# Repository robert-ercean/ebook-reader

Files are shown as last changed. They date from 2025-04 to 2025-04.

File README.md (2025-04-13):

# Block Diagram
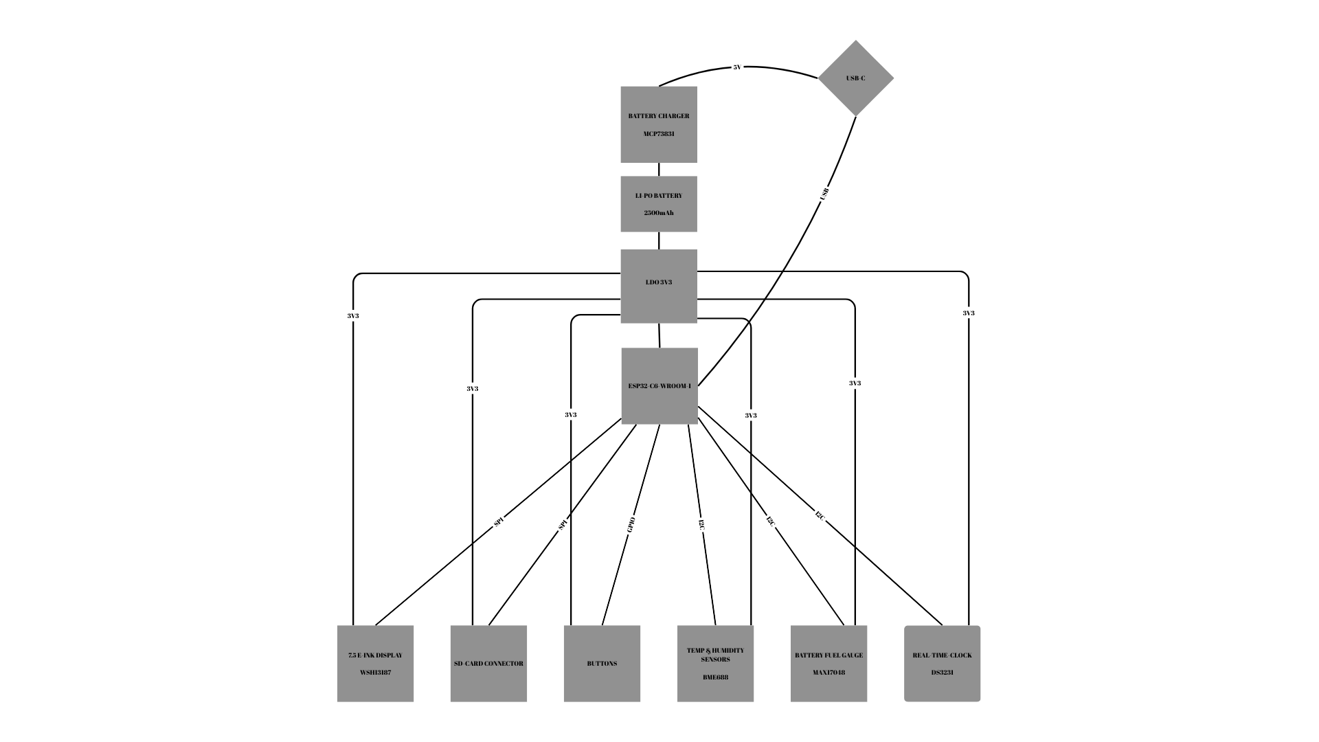
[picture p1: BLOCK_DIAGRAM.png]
Block Diagram


# Hardware Features – Detailed Description

## 1. Microcontroller – ESP32-C6

- **Processor:** 32-bit RISC-V core, clocked up to 160 MHz.
- **Memory:** 512KB internal SRAM and 8MB external flash memory (model W25Q512JVEIQ).
- **Connectivity:** Supports Wi-Fi 6 (802.11ax), Bluetooth Low Energy 5, and USB 2.0 (full-speed).
- **Interfaces:** SPI, I²C, UART, and multiple available GPIOs.
- **Power Efficiency:** Power-saving modes, including deep sleep.

## 2. E-Paper Display – 7.5”

- **Model:** Waveshare or equivalent, with a resolution of 800×480 pixels.
- **Connection:** 4-wire SPI plus control pins (CS, DC, RST, BUSY).
- **Power Consumption:** Very low in static mode; during refresh, consumption ranges between 15–25mA.

## 3. Environmental Sensor – BME688

- **Measurements:** Temperature, relative humidity, atmospheric pressure, and air quality (eCO2/VOC).
- **Interface:** I²C protocol at 400kHz (SDA/SCL).
- **Power Consumption:** Approx. 2.1µA in standby, with peaks of a few mA when active.

## 4. Power Supply and Management System

- **Battery:** Li-Po 3.7V, 2500mAh capacity.
- **Charging:** MCP73831 – simple and reliable IC for USB-C charging, up to 1A.
- **Monitoring:** MAX17048 – fuel gauge providing voltage and battery level data.
- **Voltage Regulation:** LDO such as XC6220A331MR-G, for a stable 3.3V output.

**Why these components?**
- MCP73831 offers a compact and efficient solution.
- MAX17048 enables precise battery monitoring and low-level warnings.

## 5. Buttons – 3 units

- **Type:** Tactile switch (Panasonic or similar).
- **Purpose:** Menu navigation, page turning, option selection.
- **Connection:** To GPIOs, with hardware (RC) or software debouncing.

## 6. USB-C Connector

- **Purpose:** Power/charging + data transfer via USB 2.0.
- **Protection:** ESD (e.g., USBLC6-2SC6Y) and termination resistors.
- **Options:** Supports firmware updates via USB or OTA via Wi-Fi.

## 7. Qwiic Interface (I²C)

- **Pins:** VCC, GND, SDA, SCL.
- **Functionality:** Quick expansion with additional I²C sensors/modules.

## 8. SD Card Slot – 112A-TAAR-R03

- **Purpose:** Storing e-books, logs, or firmware files.
- **Connection:** SPI or SDIO, depending on implementation.

## 9. Real-Time Clock – DS3231

- **Purpose:** Precise timekeeping, even without main power.
- **Communication:** I²C (shared with other sensors).
- **Backup:** Supercapacitor or secondary battery.

## 10. Additional Memory

- **Model:** W25Q512JVEIQ – external flash memory.
- **Connection:** Dedicated SPI (quad SPI) for firmware and large files.

---

# 4. ESP32-C6 Pin Allocation

| ESP32-C6 Pin | Signal | Detailed |
|---|---|---|
| GPIO1 | I²C SDA | Data line for sensors and RTC |
| GPIO2 | I²C SCL | Clock line for I²C interface |
| GPIO5 | SPI MISO | Data input from e-paper |
| GPIO6 | SPI MOSI | Data output to e-paper |
| GPIO7 | SPI CLK | Clock signal for SPI |
| GPIO8 | SPI CS (e-paper) | Chip select for display |
| GPIO9 | E-paper DC | Switch between data and command modes |
| GPIO10 | E-paper RST | Hardware reset for the display |
| GPIO11 | E-paper BUSY | Status signal (busy/free) |
| GPIO12 | Button 1 | Digital input for NEXT |
| GPIO13 | Button 2 | Digital input for PREV |
| GPIO14 | Button 3 | Digital input for OK/MENU |
| GPIO15 | MAX17048 ALERT (optional) | Low battery alert |
| GPIO16 | USB D+ | USB data line (fixed pin) |
| GPIO17 | USB D- | USB data line (fixed pin) |
| GPIO18 | Status LED (optional) | Visual indicator for various states |
| GPIO19 | SD Card CS | Chip select for SD card (SPI) |
| GPIO20 | SD Card MISO | Data received from SD card |
| GPIO21 | SD Card MOSI | Data sent to SD card |
| GPIO4 | SD Card CLK | SPI clock line for SD communication |

---

# Power Consumption Estimate

| Module | Typical Consumption |
|---|---|
| ESP32-C6 active | ~80mA with Wi-Fi / <10mA idle |
| E-paper (refresh) | 15–25mA |
| BME688 active | up to 3.6mA / 2.1µA standby |
| MAX17048 | Approx. 50µA |
| DS3231 | ~3.5mA active / <1µA backup |
| MCP73831 | Varies based on charging current|

**Usage Scenarios:**
- In **deep sleep**, total consumption can drop below 100µA.
- In active mode with Wi-Fi and screen refresh, consumption may reach 100–150mA.
- A 2500mAh battery allows for **weeks of operation** in predominantly passive mode (static display, infrequent Wi-Fi activity).

---

# Bill of Materials:

| Component | Type | Marketplace | Datasheet |
|---|---|---|---|
| EAGLE-LTSPICE_CC0402 | Capacitor | [Link](https://eu.mouser.com/ProductDetail/KEMET/C0402C475K8PACTU?qs=ulEaXIWI0c9ebKRT3r3htg%3D%3D) | [Datasheet](https://eu.mouser.com/datasheet/2/447/KEM_C1006_X5R_SMD-3316465.pdf) |
| ESP32_WROVER_EAGLE-LTSPICE_RR0402 | Resistor | [Link](https://eu.mouser.com/ProductDetail/Vishay-Beyschlag/MCS04020D9101BE000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) | [Datasheet](https://www.vishay.com/docs/28700/mcx0x0xpre.pdf) |
| RCL_CPOL-EUCT3528 | Capacitor | [Link](https://eu.mouser.com/ProductDetail/Nichicon/LGN2W101MELA25?qs=Fe64Qgzkstf1zMszMsgRoA%3D%3D) | [Datasheet](https://eu.mouser.com/datasheet/2/293/e_lgn-3082370.pdf) |
| ADAFRUIT_LEDCHIP-LED0603 | LED | [Link](https://eu.mouser.com/ProductDetail/ams-OSRAM/KG-EELP41.22-PHRH-35-A8J8-20-R18?qs=ZcfC38r4Posajg8ZvCDQkg%3D%3D) | [Datasheet](https://eu.mouser.com/datasheet/2/588/KG_EELP41_22_EN-3572852.pdf) |
| CPH3225A | Capacitor | [Link](https://eu.mouser.com/ProductDetail/Seiko-Semiconductors/CPH3225A?qs=3etwrb1wR%252BhUOph6lAO7eg%3D%3D) | [Datasheet](https://eu.mouser.com/datasheet/2/360/Seiko_Instruments_MicroBattery_E_20230330_2024Jan_-3561061.pdf) |
| ESP32_WROVER_SPARKFUN-DISCRETESEMI_MOSFET_PCH-DMG2305UX-7 | Transistor | [Link](https://eu.mouser.com/ProductDetail/Diodes-Incorporated/DMG2305UX-7?qs=L1DZKBg7t5F%2FNBHrjfxC%252Bg%3D%3D) | [Datasheet](https://www.diodes.com/assets/Datasheets/DMG2305UX.pdf) |
| ESP32_WROVER_AVX---SD0805S020S1R0_AVX_SD0805S020S1R0_0_0AVX_SD0805S020S1R0_0_0 | Diode | [Link](https://eu.mouser.com/ProductDetail/ROHM-Semiconductor/SCS310AMC7G?qs=iLKYxzqNS75xiccEgNnX2g%3D%3D) | [Datasheet](https://fscdn.rohm.com/en/products/databook/datasheet/discrete/sic/sbd/scs310am-e.pdf) |
| SI1308EDL-T1-GE3 | Transistor | [Link](https://eu.mouser.com/ProductDetail/Vishay-Semiconductors/SI1308EDL-T1-GE3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) | [Datasheet](https://www.vishay.com/docs/63399/si1308edl.pdf) |
| ESP32C6_VARISTORCN1812 | Varistor | [Link](https://eu.mouser.com/ProductDetail/Schurter/PFMF.050.2?qs=1auRipcfynCums5v1iucSA%3D%3D) | [Datasheet](https://eu.mouser.com/datasheet/2/358/typ_PFMF-1275918.pdf) |
| ESP32_WROVER_BME680_BME680 | Integrated Environmental Unit | [Link](https://eu.mouser.com/ProductDetail/M5Stack/U001-C?qs=e8oIoAS2J1R2mB7ZY1%252BSZg%3D%3D) | [Datasheet](https://docs.m5stack.com/en/unit/envIII) |
| ESP32-C6-WROOM-1-N8 | MicroController | [Link](https://eu.mouser.com/ProductDetail/Espressif-Systems/ESP32-C6?qs=Imq1NPwxi75noDtUpuVuWw%3D%3D) | [Datasheet](https://eu.mouser.com/datasheet/2/891/esp32_c6_datasheet_en-3304070.pdf) |
| 744043680IND_4828-WE-TPC_WRE | Inductor | [Link](https://eu.mouser.com/ProductDetail/Wurth-Elektronik/744043680?qs=PGXP4M47uW6VkZq%252BkzjrHA%3D%3D) | [Datasheet](https://www.we-online.com/components/products/datasheet/744043680.pdf) |
| SI1308EDL-T1-GE3 | Transistor | [Link](https://eu.mouser.com/ProductDetail/Vishay-Semiconductors/SI1308EDL-T1-GE3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) | [Datasheet](https://www.vishay.com/docs/63399/si1308edl.pdf) |
| BD5229G-TR | Voltage Detector | [Link](https://eu.mouser.com/ProductDetail/ROHM-Semiconductor/BD5229G-TR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) | [Datasheet](https://fscdn.rohm.com/en/products/databook/datasheet/ic/power/voltage_detector/bd52xxg-e.pdf) |
| DS3231SN# | RTC Module | [Link](https://eu.mouser.com/ProductDetail/Analog-Devices-Maxim-Integrated/DS3231SN?qs=1eQvB6Dk1vhUlr8%2FOrV0Fw%3D%3D) | [Datasheet](https://eu.mouser.com/datasheet/2/609/DS3231-3421123.pdf) |
| USBLC6-2SC6Y | ESD Protection | [Link](https://eu.mouser.com/ProductDetail/STMicroelectronics/USBLC6-2SC6Y?qs=gNDSiZmRJS%2FOgDexvXkdow%3D%3D) | [Datasheet](https://eu.mouser.com/datasheet/2/389/usblc6_2sc6y-1852505.pdf) |
| W25Q512JVEIQ | Flash Memory | [Link](https://eu.mouser.com/ProductDetail/Winbond/W25Q512JVEIQ?qs=l7cgNqFNU1jw6svr3at6tA%3D%3D) | [Datasheet](https://eu.mouser.com/datasheet/2/949/Winbond_W25Q512JV_Datasheet-3240039.pdf) |
| SAMACSYS_PARTS_USB4110-GF-A | USB Connector | [Link](https://eu.mouser.com/ProductDetail/GCT/USB4110-GF-A?qs=KUoIvG%2F9IlYiZvIXQjyJeA%3D%3D) | [Datasheet](https://eu.mouser.com/datasheet/2/837/GCT_USB4110_Product_Drawing___20k_cycles-3455479.pdf) |
| FH34SRJ | E-Paper Display Header | [Link](https://eu.mouser.com/ProductDetail/Hirose-Connector/FH34SRJ-7S-0.5SH50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) | [Datasheet](https://eu.mouser.com/datasheet/2/185/FH34SRJ_7S_0_5SH_50__CL0580_1200_0_50_2DDrawing_00-1615127.pdf) |
| MAX17048G+T10 | Battery Management | [Link](https://eu.mouser.com/ProductDetail/Analog-Devices-Maxim-Integrated/MAX17048G%2bT10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) | [Datasheet](https://eu.mouser.com/datasheet/2/609/MAX17048_MAX17049-3469099.pdf) |
| MCP73831 | Battery Controller | [Link](https://eu.mouser.com/ProductDetail/Microchip-Technology/MCP73831T-2ATI-MC?qs=yUQqVecv4qs9k7ug0bEXiw%3D%3D) | [Datasheet](https://eu.mouser.com/datasheet/2/268/MCP73831_Family_Data_Sheet_DS20001984H-3441711.pdf) |
| 112A-TAAR-R03_ATTEND | SD Card Mount | [Link](https://store.comet.srl.ro/Catalogue/Product/43497/) | [Datasheet](https://store.comet.srl.ro/Catalogue/Product/43497/) |
| XC6220A331MR-G | LDO Voltage Regulator | [Link](https://eu.mouser.com/ProductDetail/Torex-Semiconductor/XC6220A331MR-G?qs=AsjdqWjXhJ8ZSWznL1J0gg%3D%3D) | [Datasheet](https://eu.mouser.com/datasheet/2/760/xc6220-3371556.pdf) |

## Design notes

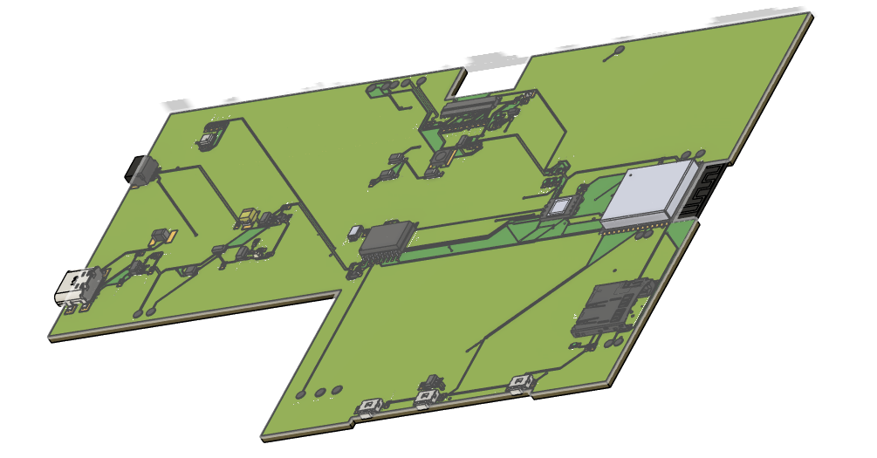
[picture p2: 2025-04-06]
Images/PCB/Board_1.png

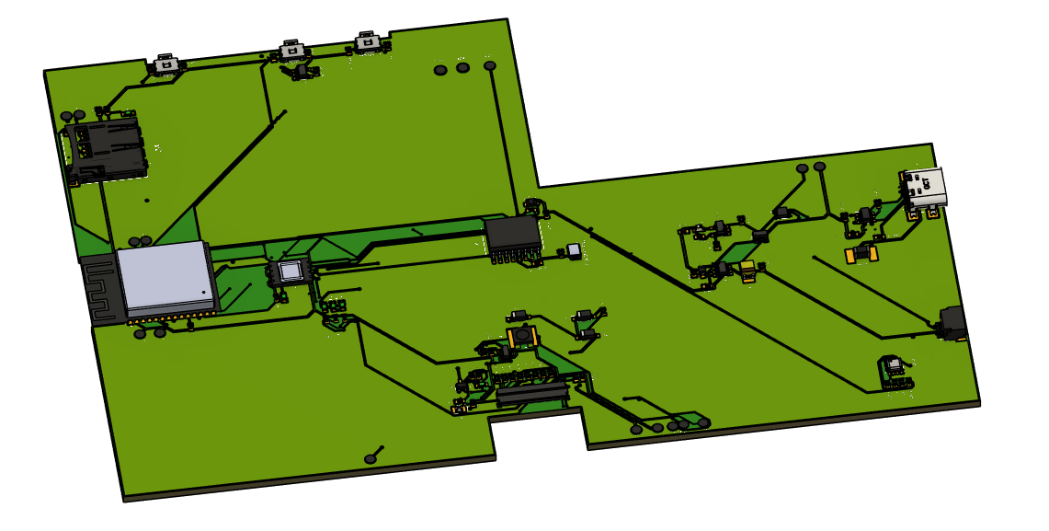
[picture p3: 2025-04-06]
Images/PCB/Board.png

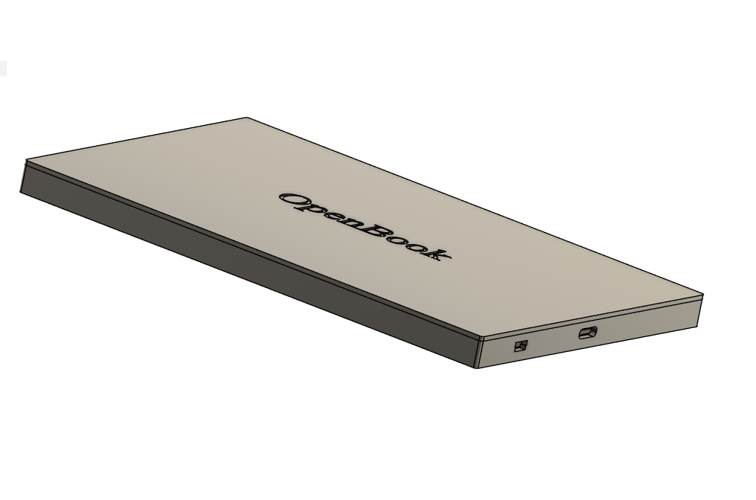
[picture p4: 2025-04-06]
Images/Device/Device_2.png

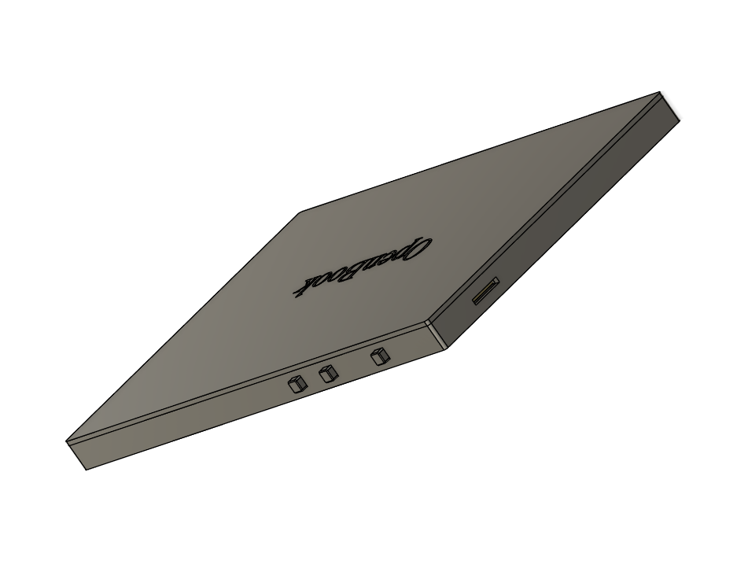
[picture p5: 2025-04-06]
Images/Device/Device_3.png

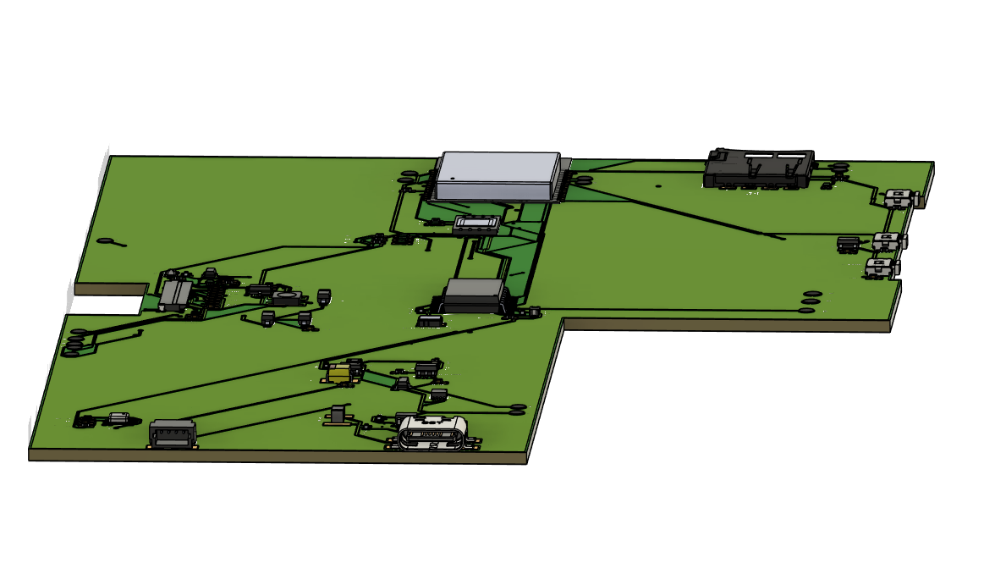
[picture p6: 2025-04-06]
Images/PCB/Board_2.png

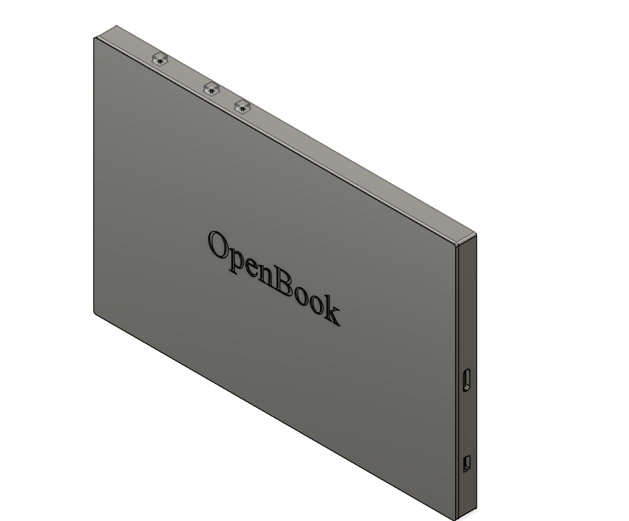
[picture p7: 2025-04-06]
Images/Device/Device.png

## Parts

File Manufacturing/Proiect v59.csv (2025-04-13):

Qty | Value | Device | Package | Parts | Description | ARROW_PART_NUMBER | ARROW_PRICE-STOCK | AVAILABILITY | CENTROID_NOT_SPECIFIED | CHECK_PRICES | COPYRIGHT | DATASHEET | DESCRIPTION | DIGIKEY_DESCRIPTION | DIGIKEY_PART_NUMBER | HEIGHT | LEAD_FREE | MANUFACTURER_NAME | MANUFACTURER_PART_NUMBER | MF | MFR_NAME | MOUSER_PART_NUMBER | MOUSER_PRICE-STOCK | MOUSER_TESTING_PART_NUMBER | MOUSER_TESTING_PRICE-STOCK | MP | MPN | PACKAGE | POPULARITY | PREFIX | PRICE | PROD_ID | PURCHASE-URL | ROHS | SNAPEDA_LINK | SPICEMODEL | SPICEPREFIX | TEMPERATURE_RANGE_HIGH | TEMPERATURE_RANGE_LOW | TP_SIGNAL_NAME | VALUE
1 |  | ADAFRUIT_LEDCHIP-LED0603 | ADAFRUIT_CHIP-LED0603 | CHG_LED | LED
1 |  | EAGLE-LTSPICE_CC0402 | EAGLE-LTSPICE_C0402 | C1_BAT | CAPACITOR, European symbol |  |  |  |  |  |  |  |  |  |  |  |  |  |  |  |  |  |  |  |  |  |  |  |  |  |  |  |  |  |  | NONE | C
1 |  | RCL_CPOL-EUCT3528 | RCL_CT3528 | C3 | POLARIZED CAPACITOR, European symbol |  |  |  |  |  |  |  |  |  |  |  |  |  |  |  |  |  |  |  |  |  |  |  | 0 |  |  |  |  |  |  |  | C
1 |  | SJ | SJ | SJ1 | SMD solder JUMPER |  |  |  |  |  |  |  |  |  |  |  |  |  |  |  |  |  |  |  |  |  |  |  | 3
1 | 0.1uF/50V | EAGLE-LTSPICE_CC0402 | EAGLE-LTSPICE_C0402 | EPD_C5 | CAPACITOR, European symbol |  |  |  |  |  |  |  |  |  |  |  |  |  |  |  |  |  |  |  |  |  |  |  |  |  |  |  |  |  |  | NONE | C
1 | 0.47 | ESP32_WROVER_EAGLE-LTSPICE_RR0402 | ESP32_WROVER_EAGLE-LTSPICE_R0402 | R3 | RESISTOR, European symbol |  |  |  |  |  |  |  |  |  |  |  |  |  |  |  |  |  |  |  |  |  |  |  |  |  |  |  |  |  |  | NONE | R
1 | 100K | ESP32_WROVER_EAGLE-LTSPICE_RR0402 | ESP32_WROVER_EAGLE-LTSPICE_R0402 | R1_PWRUSB | RESISTOR, European symbol |  |  |  |  |  |  |  |  |  |  |  |  |  |  |  |  |  |  |  |  |  |  |  |  |  |  |  |  |  |  | NONE | R
8 | 100nF | EAGLE-LTSPICE_CC0402 | EAGLE-LTSPICE_C0402 | C1, C2, C4_USB, C6, C8, C9, C10, C_DELAY | CAPACITOR, European symbol |  |  |  |  |  |  |  |  |  |  |  |  |  |  |  |  |  |  |  |  |  |  |  |  |  |  |  |  |  |  | NONE | C
16 | 10K | ESP32_WROVER_EAGLE-LTSPICE_RR0402 | ESP32_WROVER_EAGLE-LTSPICE_R0402 | R1, R1_PINH, R1_PINH1, R2-PINH, R2-PINH1, R4, R5, R6, R7, R8, R9, R10, R_BOOT, R_CHANGE, R_CL1, R_RESET | RESISTOR, European symbol |  |  |  |  |  |  |  |  |  |  |  |  |  |  |  |  |  |  |  |  |  |  |  |  |  |  |  |  |  |  | NONE | R
1 | 10uF | EAGLE-LTSPICE_CC0402 | EAGLE-LTSPICE_C0402 | C7 | CAPACITOR, European symbol |  |  |  |  |  |  |  |  |  |  |  |  |  |  |  |  |  |  |  |  |  |  |  |  |  |  |  |  |  |  | NONE | C
1 | 112A-TAAR-R03_ATTEND | 112A-TAAR-R03_ATTEND | 112ATAARR03ATTEND | J4 | Micro SD Card Socket, Push-Push Type, Top Mount, SMT, H=1.83mm, 10u |  |  |  |  |  |  |  | Micro SD Card Socket | Push-Push Type | Top Mount | SMT | H=1.83mm | 10u |  |  | 1.9mm |  | ATTEND | 112A-TAAR-R03 ATTEND
1 | 15 | ESP32_WROVER_EAGLE-LTSPICE_RR0402 | ESP32_WROVER_EAGLE-LTSPICE_R0402 | R_CAPACITOR | RESISTOR, European symbol |  |  |  |  |  |  |  |  |  |  |  |  |  |  |  |  |  |  |  |  |  |  |  |  |  |  |  |  |  |  | NONE | R
1 | 1uF | EAGLE-LTSPICE_CC0402 | EAGLE-LTSPICE_C0402 | C5 | CAPACITOR, European symbol |  |  |  |  |  |  |  |  |  |  |  |  |  |  |  |  |  |  |  |  |  |  |  |  |  |  |  |  |  |  | NONE | C
9 | 1uF/50V | EAGLE-LTSPICE_CC0402 | EAGLE-LTSPICE_C0402 | EPD_C1, EPD_C2, EPD_C6, EPD_C7, EPD_C8, EPD_C9, EPD_C10, EPD_C11, EPD_C12 | CAPACITOR, European symbol |  |  |  |  |  |  |  |  |  |  |  |  |  |  |  |  |  |  |  |  |  |  |  |  |  |  |  |  |  |  | NONE | C
1 | 2.2 | ESP32_WROVER_EAGLE-LTSPICE_RR0402 | ESP32_WROVER_EAGLE-LTSPICE_R0402 | R2 | RESISTOR, European symbol |  |  |  |  |  |  |  |  |  |  |  |  |  |  |  |  |  |  |  |  |  |  |  |  |  |  |  |  |  |  | NONE | R
1 | 200 | ESP32_WROVER_EAGLE-LTSPICE_RR0402 | ESP32_WROVER_EAGLE-LTSPICE_R0402 | R1_BAT | RESISTOR, European symbol |  |  |  |  |  |  |  |  |  |  |  |  |  |  |  |  |  |  |  |  |  |  |  |  |  |  |  |  |  |  | NONE | R
2 | 20V/4.2A/52mO/1.4W | ESP32_WROVER_SPARKFUN-DISCRETESEMI_MOSFET_PCH-DMG2305UX-7 | ESP32_WROVER_SPARKFUN-DISCRETESEMI_SOT23-3 | Q1, Q2 | P-channel MOSFETs |  |  |  |  |  |  |  |  |  |  |  |  |  |  |  |  |  |  |  |  |  |  |  |  |  |  | TRAN-14388 |  |  |  |  |  |  |  |  | 20V/4.2A/52mO/1.4W
1 | 2K | ESP32_WROVER_EAGLE-LTSPICE_RR0402 | ESP32_WROVER_EAGLE-LTSPICE_R0402 | R2_BAT | RESISTOR, European symbol |  |  |  |  |  |  |  |  |  |  |  |  |  |  |  |  |  |  |  |  |  |  |  |  |  |  |  |  |  |  | NONE | R
4 | 4.7uF | EAGLE-LTSPICE_CC0402 | EAGLE-LTSPICE_C0402 | C1_BAT1, C1_BAT2, C2_BAT, C5_USB | CAPACITOR, European symbol |  |  |  |  |  |  |  |  |  |  |  |  |  |  |  |  |  |  |  |  |  |  |  |  |  |  |  |  |  |  | NONE | C
1 | 4.7uF/25V | EAGLE-LTSPICE_CC0402 | EAGLE-LTSPICE_C0402 | C4 | CAPACITOR, European symbol |  |  |  |  |  |  |  |  |  |  |  |  |  |  |  |  |  |  |  |  |  |  |  |  |  |  |  |  |  |  | NONE | C
2 | 5K1 | ESP32_WROVER_EAGLE-LTSPICE_RR0402 | ESP32_WROVER_EAGLE-LTSPICE_R0402 | R2-USB, R2-USB1 | RESISTOR, European symbol |  |  |  |  |  |  |  |  |  |  |  |  |  |  |  |  |  |  |  |  |  |  |  |  |  |  |  |  |  |  | NONE | R
1 | 68uH | 744043680IND_4828-WE-TPC_WRE | IND_4828-WE-TPC_WRE | L1 |  |  |  |  |  |  | Copyright (C) 2024 Ultra Librarian. All rights reserved. |  |  |  |  |  |  |  | 744043680 |  | Wurth Electronics
1 | BD5229G-TR | BD5229G-TR | SOT95P280X125-5N | IC2 | Voltage Detector with Adjustable Delay Time: CMOS processes are utilized to develop high precision, low current consumption CMOS reset ICs that allow arbitrary setting of the delay time. The extensive lineup includes both Nch Open Drain and CMOS output types in a wide range of detection voltages (from 2.3V to 6.0V, in 0.1V steps), enabling selection of the ideal solution based on customer requirements. In addition, the entire series is of course both lead-free and RoHS-compliant. |  |  |  |  |  |  |  | Voltage Detector with Adjustable Delay Time: CMOS processes are utilized to develop high precision | low current consumption CMOS reset ICs that allow arbitrary setting of the delay time. The extensive lineup includes both Nch Open Drain and CMOS output types in a wide range of detection voltages (from 2.3V to 6.0V | in 0.1V steps) | enabling selection of the ideal solution based on customer requirements. In addition | the entire series is of course both lead-free and RoHS-compliant. |  |  | 1.25mm |  | ROHM Semiconductor | BD5229G-TR |  |  | 755-BD5229G-TR | https://www.mouser.co.uk/ProductDetail/ROHM-Semiconductor/BD5229G-TR?qs=4kLU8WoGk0vvnhrrYwdszw%3D%3D
3 | BUTTON_CUSYOMV1 | BUTTON_CUSYOMV1 | MYBUTTON | BOOT_BUTTON, CHANGE_BUTTON, RESET_BUTTON
1 | CPH3225A | CPH3225A | CAPCP3225X100N | C10_SUPERCAP | Cap 0.011F 3.3V 1210 Flat Check availability |  |  | Not in stock |  | https://www.snapeda.com/parts/CPH3225A/Seiko+Instruments/view-part/?ref=eda |  |  | 11 mF (EDLC) Supercapacitor 3.3 V 1210 (3225 Metric) - - |  |  |  |  |  |  | Seiko Instruments |  |  |  |  |  | CPH3225A |  | 1210 Seiko |  |  | None |  | https://www.snapeda.com/api/url_track_click_mouser/?unipart_id=562593&manufacturer=Seiko Instruments&part_name=CPH3225A&search_term=None |  | https://www.snapeda.com/parts/CPH3225A/Seiko+Instruments/view-part/?ref=snap
1 | DS3231SN# | DS3231SN# | SOIC127P1032X265-16N | U3 | Real Time Clock Serial 16-Pin SOIC W T/R Check availability |  |  | In Stock |  | https://www.snapeda.com/parts/DS3231SN%23/Analog+Devices/view-part/?ref=eda |  |  | Extremely Accurate I²C-Integrated RTC/TCXO/Crystal |  |  |  |  |  |  | Analog Devices |  |  |  |  |  | DS3231SN# |  | SOIC-16 Maxim |  |  | None |  | https://www.snapeda.com/api/url_track_click_mouser/?unipart_id=99048&manufacturer=Analog Devices&part_name=DS3231SN#&search_term=None |  | https://www.snapeda.com/parts/DS3231SN%23/Analog+Devices/view-part/?ref=snap
1 | ESP32-C6-WROOM-1-N8 | ESP32-C6-WROOM-1-N8 | XCVR_ESP32-C6-WROOM-1-N8 | U2 | Check availability |  |  | In Stock |  | https://www.snapeda.com/parts/ESP32-C6-WROOM-1-N8/Espressif+Systems/view-part/?ref=eda |  |  | Multiprotocol Modules ESP32-C6 module | Wi-Fi 6 in 2.4 GHz band | Bluetooth 5 | Zigbee 3.0 and Thread. ESP34-WROOM Compatible - ENGINEERING SAMPLE |  |  |  |  |  |  | Espressif Systems |  |  |  |  |  | ESP32-C6-WROOM-1-N8 |  | None |  |  | None |  |  |  | https://www.snapeda.com/parts/ESP32-C6-WROOM-1-N8/Espressif+Systems/view-part/?ref=snap
1 | ESP32C6_VARISTORCN1812 | ESP32C6_VARISTORCN1812 | ESP32C6_VARISTOR_CT/CN1812 | PFMF.050.1 | VARISTOR |  |  |  |  |  |  |  |  |  |  |  |  |  |  |  |  |  |  |  |  |  |  |  | 0
2 | ESP32_WROVER_AVX---SD0805S020S1R0_AVX_SD0805S020S1R0_0_0AVX_SD0805S020S1R0_0_0 | ESP32_WROVER_AVX---SD0805S020S1R0_AVX_SD0805S020S1R0_0_0AVX_SD0805S020S1R0_0_0 | ESP32_WROVER_AVX---SD0805S020S1R0_AVX_SD0805S020S1R0_0 | D1, D7 | Schottky Barrier Rectifier Diode |  |  |  | No |  |  | http://datasheets.avx.com/schottky.pdf |  | DIODE SCHOTTKY 20V 1A 0805 | 478-7800-1-ND |  | yes |  |  | AVX |  | 581-SD0805S020S1R0 |  |  |  |  |  | 0805 (2012 metric) |  | D |  |  |  | yes |  |  |  | +125°C | -55°C
1 | ESP32_WROVER_BME680_BME680 | ESP32_WROVER_BME680_BME680 | ESP32_WROVER_BME680_PSON80P300X300X100-8N | SENSOR2 | Integrated Environmental Unit |  |  | Unavailable |  |  |  |  | Integrated Environmental Unit |  |  |  |  |  |  | Bosch Sensortec |  |  |  |  |  | BME680 |  | LGA-8 Bosch Tools |  |  | None
1 | ESP32_WROVER_SPARKFUN-IC-POWER_MCP73831 | ESP32_WROVER_SPARKFUN-IC-POWER_MCP73831 | ESP32_WROVER_SPARKFUN-IC-POWER_SOT23-5 | MCP_73831 | MCP73831T Li-Ion, Li-Pol Controller |  |  |  |  |  |  |  |  |  |  |  |  |  |  |  |  |  |  |  |  |  |  |  |  |  |  | IC-09995
1 | FH34SRJ-24S-0.5SH_99_ | FH34SRJ-24S-0.5SH_99_ | FH34SRJ24S05SH99 | J1 | (0.50mm) Surface Mount, Right Angle |  |  |  |  |  |  |  | 24 Position FFC | FPC Connector Contacts | (0.50mm) Surface Mount | Right Angle |  |  | 1.1mm |  | Hirose | FH34SRJ-24S-0.5SH(99) |  |  | 798-FH34SRJ24S05SH99 | https://www.mouser.co.uk/ProductDetail/Hirose-Connector/FH34SRJ-24S-0.5SH99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
1 | MAX17048G+T10 | MAX17048G+T10 | SON50P200X200X80-9N | U1 | Check availability |  |  | In Stock |  | https://www.snapeda.com/parts/MAX17048G+T10/Analog+Devices/view-part/?ref=eda |  |  | 3µA 1-Cell/2-Cell Fuel Gauge with ModelGauge |  |  |  |  |  |  | Analog Devices |  |  |  |  |  | MAX17048G+T10 |  | TDFN-8 Maxim |  |  | None |  | https://www.snapeda.com/api/url_track_click_mouser/?unipart_id=329239&manufacturer=Analog Devices&part_name=MAX17048G+T10&search_term=None |  | https://www.snapeda.com/parts/MAX17048G+T10/Analog+Devices/view-part/?ref=snap
3 | MBR0530 | MBR0530 | SOD3716X135N | D3, D4, D5 | ON SEMICONDUCTOR - MBR0530 - DIODE, SCHOTTKY, 0.5A, 30V, SOD-123 |  |  | In Stock |  | https://www.snapeda.com/parts/MBR0530/Onsemi/view-part/?ref=eda |  |  | Diode Schottky 30 V 500mA Surface Mount SOD-123 |  |  |  |  |  |  | ON Semiconductor |  |  |  |  |  | MBR0530 |  | SOD-123-2 ON Semiconductor |  |  | None |  | https://www.snapeda.com/api/url_track_click_mouser/?unipart_id=179458&manufacturer=ON Semiconductor&part_name=MBR0530&search_term=None |  | https://www.snapeda.com/parts/MBR0530/Onsemi/view-part/?ref=snap
6 | PGB1010603MR | PGB1010603MR | DIOC1608X36N | D6, D8, D9, D10, D11, D12 | Check availability |  |  | In Stock |  | https://www.snapeda.com/parts/PGB1010603MR/Littelfuse/view-part/?ref=eda |  |  | 150V (Typ) Clamp - Ipp Tvs Diode Surface Mount 0603 (1608 Metric) |  |  |  |  |  |  | Littelfuse Inc. |  |  |  |  |  | PGB1010603MR |  | 0603 Littelfuse Inc. |  |  | None |  | https://www.snapeda.com/api/url_track_click_mouser/?unipart_id=5659453&manufacturer=Littelfuse Inc.&part_name=PGB1010603MR&search_term=None |  | https://www.snapeda.com/parts/PGB1010603MR/Littelfuse/view-part/?ref=snap
1 | QWIIC_RIGHT_ANGLE | QWIIC_CONNECTORJS-1MM | JST04_1MM_RA | J3 | SparkFun I2C Standard Qwiic Connector |  |  |  |  |  |  |  |  |  |  |  |  |  |  |  |  |  |  |  |  |  |  |  |  |  |  | CONN-13694 |  |  |  |  |  |  |  |  | QWIIC_RIGHT_ANGLE
1 | SAMACSYS_PARTS_USB4110-GF-ACPLM | SAMACSYS_PARTS_USB4110-GF-ACPLM | SAMACSYS_PARTS_USB4110GFA | J2 | CONN USB 2.0 TYPE-C R/A SMT
1 | SI1308EDL-T1-GE3 | SI1308EDL-T1-GE3 | SOT65P210X110-3N | Q3 | MOSFET N-Ch 30V 1.5A TrenchFET SC70 Vishay Si1308EDL-T1-GE3 N-channel MOSFET Transistor, 1.5 A, 30 V, 3-Pin SC-70 |  |  | In Stock |  | https://www.snapeda.com/parts/SI1308EDL-T1-GE3/Vishay+Siliconix/view-part/?ref=eda |  |  | Si1308EDL-T1-GE3 N-channel MOSFET Transistor | 1.5 A | 30 V | 3-Pin SC-70 | Siliconix / Vishay SI1308EDL-T1-GE3 |  |  |  |  |  |  | Vishay Siliconix |  |  |  |  |  | SI1308EDL-T1-GE3 |  | SOT-323 Vishay Semiconductor |  |  | None |  | https://www.snapeda.com/api/url_track_click_mouser/?unipart_id=274603&manufacturer=Vishay Siliconix&part_name=SI1308EDL-T1-GE3&search_term=None |  | https://www.snapeda.com/parts/SI1308EDL-T1-GE3/Vishay+Siliconix/view-part/?ref=snap
17 | TPTP20R | TPTP20R | TP20R | TP1, TP2, TP3, TP4, TP5, TP6, TP7, TP8, TP9, TP10, TP11, TP12, TP13, TP14, TP15, TP16, TP17 | Test pad |  |  |  |  |  |  |  |  |  |  |  |  |  |  |  |  |  |  |  |  |  |  |  | 2
1 | USBLC6-2SC6Y | USBLC6-2SC6Y | SOT95P280X145-6N | D2 | Low Cap. ESD Protection Auto SOT-23-6 STMicroelectronics USBLC6-2SC6Y, Dual Uni-Directional TVS Diode Array, 6-Pin SOT-23 |  |  | In Stock |  | https://www.snapeda.com/parts/USBLC6-2SC6Y/STMicroelectronics/view-part/?ref=eda |  |  | 17V Clamp 5A (8/20µs) Ipp Tvs Diode Surface Mount SOT-23-6 |  |  |  |  |  |  | STMicroelectronics |  |  |  |  |  | USBLC6-2SC6Y |  | SOT-23-6 STMicroelectronics |  |  | None |  |  |  | https://www.snapeda.com/parts/USBLC6-2SC6Y/STMicroelectronics/view-part/?ref=snap
1 | W25Q512JVEIQ | W25Q512JVEIQ | SON127P600X800X80-9N | U4 | Check availability |  |  | In Stock |  | https://www.snapeda.com/parts/W25Q512JVEIQ/Winbond+Electronics/view-part/?ref=eda |  |  | FLASH - NOR Memory IC 512Mb (64M x 8) SPI - Quad I/O 133 MHz 8-WSON (8x6) |  |  |  |  |  |  | Winbond Electronics |  |  |  |  |  | W25Q512JVEIQ |  | Package |  |  | None |  |  |  | https://www.snapeda.com/parts/W25Q512JVEIQ/Winbond+Electronics/view-part/?ref=snap
1 | XC6220A331MR-G | XC6220A331MR-G | SOT95P280X120-5N | IC1 | LDO Voltage Regulators |  |  |  |  |  |  |  | LDO Voltage Regulators |  |  | 1.2mm |  | Torex | XC6220A331MR-G |  |  | 865-XC6220A331MR-G | https://www.mouser.co.uk/ProductDetail/Torex-Semiconductor/XC6220A331MR-G?qs=AsjdqWjXhJ8ZSWznL1J0gg%3D%3D

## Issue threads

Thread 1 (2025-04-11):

Schematic Review

Pepper-Dragon, 2025-04-11:
Schematic foarte bine făcut.

## ERC
Ai uitat să pui valori condesatorilor `c3` și `c1_bat`:
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

## Sugestii
Ai putea scrie in schematic numele modulelor pentru a fi mai ușor de citit:

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
(OCW Schematic) - (Schematic-ul tău)

Poți să scrii în fusion cu tool-ul de `text` din tabul `document/draw`:

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

robert-ercean, 2025-04-13:
## ✅ Fixes:
- Added values for the specified components
- Added custom names on the schematic for easier preview

Closed 2025-04-13.

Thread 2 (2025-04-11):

PCB Review

Pepper-Dragon, 2025-04-11:
Ai niste erori mici spre mari (la routing). Imi plac modelele 3d pentru card reader si ecran.

## Board
* Route-uri pentru ground
    Ai fire de ground care sunt nejustificate. Poți folosi planul de masă pentru semnalul de ground.

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
Recomand folosirea de `via-uri`  sau `via stiching` pentru a conecta planele de masa (top-bottom)
in caz de ai "insule" de plan de masa care nu se conecteaza cu restul.

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
(Nu uita sa adaugi numele semnalului)

* Traseu de putere de 0.15 mm
    Semnalul `VBAT` e  de 0.15mm in loc de 0.3mm.

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
Imi place ca ai folosit net classes.

* Foarte multe via-uri in traseele de putere

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

* Placa nu are grosimea de 1 mm (posibil problema de import la fusion)

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

* Dimensiuni PCB
   Neimportant, dar am zis sa mentionez. Latura pcb-ului de langa display header e de 9.8mm
in loc de 10.

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

## 3D PCB
* Mufele USB nu se aliniaza cu carcasa.
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

* Cateva componente nu sunt conectate cu paddurile lor
    - `Q3`
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
    - `Q2`
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
    - `pfmp.050.1`
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

* Silkscreen
    - Mufa `J3` are silkscreen-ul sub piesa
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
    - Testpad-urile nu au numele semnalului in silkscreen (poti folosi tool-ul de text sa le adaugi)
    - Silkscreen de calitate proasta (posibil problema de la fusion)
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

robert-ercean, 2025-04-13:
##✅ Fixes
- Alligned the 3D models mentioned
- Got rid of holes in the GND top & bottom planes by adding vias and vias stitching
- Fixed silkscreen for J3
- Fixed silkscreen names export quality
- Fixed missalignment for components of the final product's 3D model

Closed 2025-04-13.

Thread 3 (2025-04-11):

Readme Review

Pepper-Dragon, 2025-04-11:
Readme-ul e ok, dar in bill of materials (bom) ai cateva linkuri la [component search engine](https://componentsearchengine.com/) in loc de marketplace-uri ca [Mouser](https://ro.mouser.com/) sau [Comet](https://www.comet.srl.ro/).

robert-ercean, 2025-04-13:
## ✅ Fixes:
- Adjusted BOM to include only links for suggested marketplaces
- Added links to each component's datasheet in the BOM

Closed 2025-04-13.

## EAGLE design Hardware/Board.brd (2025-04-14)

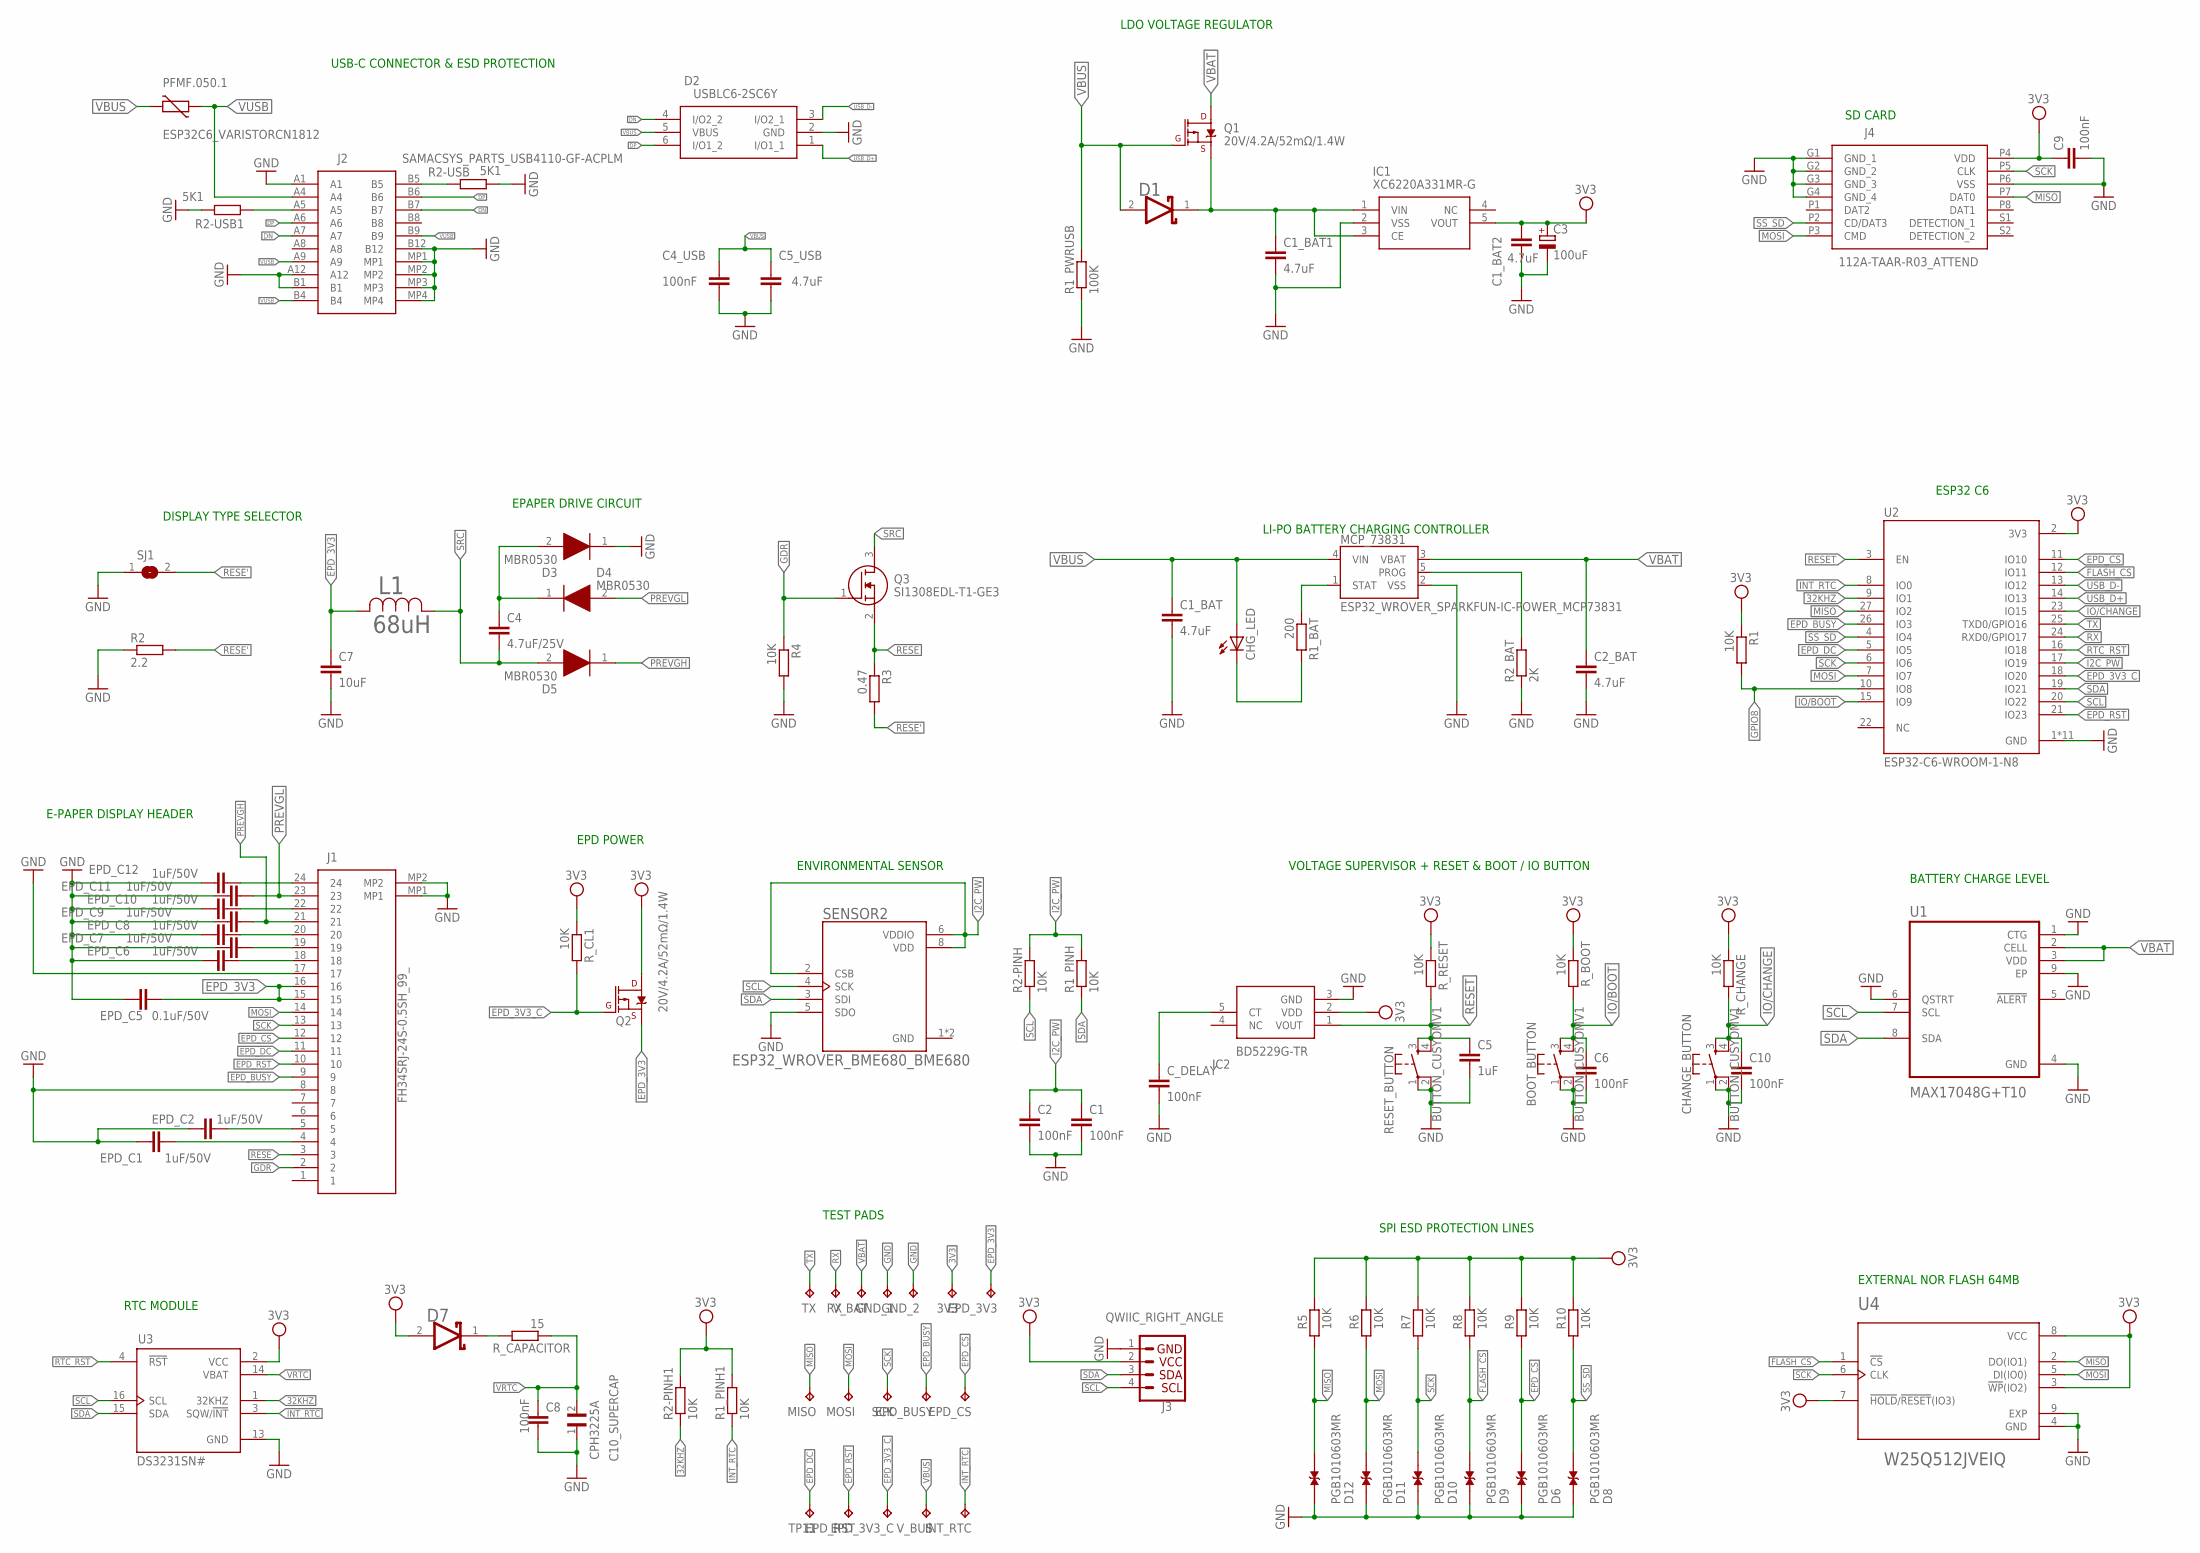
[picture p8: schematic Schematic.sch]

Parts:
3V3: TPTP20R; TP20R
BOOT_BUTTON: BUTTON_CUSYOMV1; MYBUTTON
C1, C2, C4_USB, C6, C8, C9, C10: 100nF; EAGLE-LTSPICE_C0402
C1_BAT, C1_BAT1, C1_BAT2, C2_BAT, C5_USB: 4.7uF; EAGLE-LTSPICE_C0402
C3: 100uF; RCL_CT3528
C4: 4.7uF/25V; EAGLE-LTSPICE_C0402
C5: 1uF; EAGLE-LTSPICE_C0402
C7: 10uF; EAGLE-LTSPICE_C0402
C10_SUPERCAP: CPH3225A; CAPCP3225X100N
CHANGE_BUTTON: BUTTON_CUSYOMV1; MYBUTTON
CHG_LED: ADAFRUIT_LEDCHIP-LED0603; ADAFRUIT_CHIP-LED0603
C_DELAY: 100nF; EAGLE-LTSPICE_C0402
D1, D7: ESP32_WROVER_AVX---SD0805S020S1R0_AVX_SD0805S020S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; ESP32_WROVER_AVX---SD0805S020S1R0_AVX_SD0805S020S1R0_0
D2: USBLC6-2SC6Y; SOT95P280X145-6N
D3, D4, D5: MBR0530; SOD3716X135N
D6, D8, D9, D10, D11, D12: PGB1010603MR; DIOC1608X36N
EPD_3V3, EPD_3V3_C: TPTP20R; TP20R
EPD_BUSY: TPTP20R; TP20R
EPD_C1, EPD_C2, EPD_C6, EPD_C7, EPD_C8, EPD_C9, EPD_C10, EPD_C11, EPD_C12: 1uF/50V; EAGLE-LTSPICE_C0402
EPD_C5: 0.1uF/50V; EAGLE-LTSPICE_C0402
EPD_CS: TPTP20R; TP20R
EPD_RST: TPTP20R; TP20R
GND_1, GND_2: TPTP20R; TP20R
IC1: XC6220A331MR-G; SOT95P280X120-5N
IC2: BD5229G-TR; SOT95P280X125-5N
INT_RTC: TPTP20R; TP20R
J1: FH34SRJ-24S-0.5SH_99_; FH34SRJ24S05SH99
J2: SAMACSYS_PARTS_USB4110-GF-ACPLM; SAMACSYS_PARTS_USB4110GFA
J3: QWIIC_RIGHT_ANGLE; JST04_1MM_RA
J4: 112A-TAAR-R03_ATTEND; 112ATAARR03ATTEND
L1: 68uH; IND_4828-WE-TPC_WRE
MCP_73831: ESP32_WROVER_SPARKFUN-IC-POWER_MCP73831; ESP32_WROVER_SPARKFUN-IC-POWER_SOT23-5
MISO: TPTP20R; TP20R
MOSI: TPTP20R; TP20R
PFMF.050.1: ESP32C6_VARISTORCN1812; ESP32C6_VARISTOR_CT/CN1812
Q1, Q2: 20V/4.2A/52mΩ/1.4W; ESP32_WROVER_SPARKFUN-DISCRETESEMI_SOT23-3
Q3: SI1308EDL-T1-GE3; SOT65P210X110-3N
R1, R1_PINH, R1_PINH1, R2-PINH, R2-PINH1, R4, R5, R6, R7, R8, R9, R10: 10K; ESP32_WROVER_EAGLE-LTSPICE_R0402
R1_BAT: 200; ESP32_WROVER_EAGLE-LTSPICE_R0402
R1_PWRUSB: 100K; ESP32_WROVER_EAGLE-LTSPICE_R0402
R2: 2.2; ESP32_WROVER_EAGLE-LTSPICE_R0402
R2-USB, R2-USB1: 5K1; ESP32_WROVER_EAGLE-LTSPICE_R0402
R2_BAT: 2K; ESP32_WROVER_EAGLE-LTSPICE_R0402
R3: 0.47; ESP32_WROVER_EAGLE-LTSPICE_R0402
RESET_BUTTON: BUTTON_CUSYOMV1; MYBUTTON
RX: TPTP20R; TP20R
R_BOOT: 10K; ESP32_WROVER_EAGLE-LTSPICE_R0402
R_CAPACITOR: 15; ESP32_WROVER_EAGLE-LTSPICE_R0402
R_CHANGE: 10K; ESP32_WROVER_EAGLE-LTSPICE_R0402
R_CL1: 10K; ESP32_WROVER_EAGLE-LTSPICE_R0402
R_RESET: 10K; ESP32_WROVER_EAGLE-LTSPICE_R0402
SCK: TPTP20R; TP20R
SENSOR2: ESP32_WROVER_BME680_BME680; ESP32_WROVER_BME680_PSON80P300X300X100-8N
SJ1: SJ
TP11: TPTP20R; TP20R
TX: TPTP20R; TP20R
U1: MAX17048G+T10; SON50P200X200X80-9N
U2: ESP32-C6-WROOM-1-N8; XCVR_ESP32-C6-WROOM-1-N8
U3: DS3231SN#; SOIC127P1032X265-16N
U4: W25Q512JVEIQ; SON127P600X800X80-9N
V_BAT: TPTP20R; TP20R
V_BUS: TPTP20R; TP20R

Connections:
3V3: 3V3.TP, C1_BAT2.1, C3.+, C9.1, D7.2 (ANODE), IC1.5 (VOUT), IC2.2 (VDD), J3.2, J4.P4 (VDD), Q2.3 (D), R1.1, R1_PINH1.2, R2-PINH1.2, R5.2, R6.2, R7.2, R8.2, R9.2, R10.2, R_BOOT.1, R_CHANGE.1, R_CL1.1, R_RESET.1, U2.2 (3V3), U3.2 (VCC), U4.3 (!WP!(IO2)), U4.7 (!HOLD!/!RESET!(IO3)), U4.8 (VCC)
32KHZ: R2-PINH1.1, U2.9 (IO1), U3.1 (32KHZ)
DN: D2.4 (I/O2_2), J2.A7, J2.B7
DP: D2.6 (I/O1_2), J2.A6, J2.B6
EPD_3V3: C7.1, EPD_3V3.TP, EPD_C5.1, J1.15, J1.16, L1.2, Q2.2 (S)
EPD_3V3_C: EPD_3V3_C.TP, Q2.1 (G), R_CL1.2, U2.18 (IO20)
EPD_BUSY: EPD_BUSY.TP, J1.9, U2.26 (IO3)
EPD_CS: D6.2, EPD_CS.TP, J1.12, R9.1, U2.11 (IO10)
EPD_DC: J1.11, TP11.TP, U2.5 (IO5)
EPD_RST: EPD_RST.TP, J1.10, U2.21 (IO23)
FLASH_CS: D9.2, R8.1, U2.12 (IO11), U4.1 (!CS)
GDR: J1.2, Q3.1 (G), R4.1
GND: BOOT_BUTTON.1, BOOT_BUTTON.2, C1.2, C1_BAT.2, C1_BAT1.2, C1_BAT2.2, C2.2, C2_BAT.2, C3.-, C4_USB.2, C5.2, C5_USB.2, C6.2, C7.2, C8.2, C9.2, C10.2, C10_SUPERCAP.1, CHANGE_BUTTON.1, CHANGE_BUTTON.2, C_DELAY.2, D2.2 (GND), D3.1 (K), D6.1, D8.1, D9.1, D10.1, D11.1, D12.1, EPD_C1.2, EPD_C2.2, EPD_C5.2, EPD_C6.2, EPD_C7.2, EPD_C8.2, EPD_C9.2, EPD_C10.2, EPD_C11.2, EPD_C12.2, GND_1.TP, GND_2.TP, IC1.2 (VSS), IC2.3 (GND), J1.8, J1.17, J1.MP1, J1.MP2, J2.A1, J2.A12, J2.B1, J2.B12, J2.MP1, J2.MP2, J2.MP3, J2.MP4, J3.1, J4.G1 (GND_1), J4.G2 (GND_2), J4.G3 (GND_3), J4.G4 (GND_4), J4.P6 (VSS), MCP_73831.2 (VSS), R1_PWRUSB.1, R2.1, R2-USB.2, R2-USB1.1, R2_BAT.1, R4.2, RESET_BUTTON.1, RESET_BUTTON.2, SENSOR2.1 (GND), SENSOR2.5 (SDO), SENSOR2.7 (GND), SJ1.1, U1.1 (CTG), U1.4 (GND), U1.6 (QSTRT), U1.9 (EP), U2.1 (GND), U2.28 (GND), U2.29_1 (GND), U2.29_2 (GND), U2.29_3 (GND), U2.29_4 (GND), U2.29_5 (GND), U2.29_6 (GND), U2.29_7 (GND), U2.29_8 (GND), U2.29_9 (GND), U3.13 (GND), U4.4 (GND), U4.9 (EXP)
GPIO8: R1.2, U2.10 (IO8)
I2C_PW: C1.1, C2.1, R1_PINH.2, R2-PINH.2, SENSOR2.2 (CSB), SENSOR2.6 (VDDIO), SENSOR2.8 (VDD), U2.17 (IO19)
INT_RTC: INT_RTC.TP, R1_PINH1.1, U2.8 (IO0), U3.3 (SQW/!INT)
IO/BOOT: BOOT_BUTTON.3, BOOT_BUTTON.4, C6.1, R_BOOT.2, U2.15 (IO9)
IO/CHANGE: C10.1, CHANGE_BUTTON.3, CHANGE_BUTTON.4, R_CHANGE.2, U2.23 (IO15)
MISO: D12.2, J4.P7 (DAT0), MISO.TP, R5.1, U2.27 (IO2), U4.2 (DO(IO1))
MOSI: D11.2, J1.14, J4.P3 (CMD), MOSI.TP, R6.1, U2.7 (IO7), U4.5 (DI(IO0))
unnamed: C1_BAT1.1, D1.1 (CATHODE), IC1.1 (VIN), IC1.3 (CE), Q1.2 (S)
unnamed: MCP_73831.1 (STAT), R1_BAT.1
unnamed: CHG_LED.C, R1_BAT.2
unnamed: MCP_73831.5 (PROG), R2_BAT.2
unnamed: C_DELAY.1, IC2.5 (CT)
unnamed: J2.A5, R2-USB1.2
unnamed: J2.B5, R2-USB.1
unnamed: C4.1, D3.2 (A), D4.1 (K)
unnamed: EPD_C2.1, J1.5
unnamed: EPD_C12.1, J1.24
unnamed: EPD_C1.1, J1.4
unnamed: D7.1 (CATHODE), R_CAPACITOR.2
unnamed: EPD_C10.1, J1.22
unnamed: EPD_C8.1, J1.20
unnamed: EPD_C7.1, J1.19
unnamed: EPD_C6.1, J1.18
PREVGH: D5.1 (K), EPD_C9.1, J1.21
PREVGL: D4.2 (A), EPD_C11.1, J1.23
RESE: J1.3, Q3.2 (S), R3.1
RESE': R2.2, R3.2, SJ1.2
RESET: C5.1, IC2.1 (VOUT), RESET_BUTTON.3, RESET_BUTTON.4, R_RESET.2, U2.3 (EN)
RTC_RST: U2.16 (IO18), U3.4 (!RST)
RX: RX.TP, U2.24 (RXD0/GPIO17)
SCK: D10.2, J1.13, J4.P5 (CLK), R7.1, SCK.TP, U2.6 (IO6), U4.6 (CLK)
SCL: J3.4, R2-PINH.1, SENSOR2.4 (SCK), U1.7 (SCL), U2.20 (IO22), U3.16 (SCL)
SDA: J3.3, R1_PINH.1, SENSOR2.3 (SDI), U1.8 (SDA), U2.19 (IO21), U3.15 (SDA)
SRC: C4.2, D5.2 (A), L1.1, Q3.3 (D)
SS_SD: D8.2, J4.P2 (CD/DAT3), R10.1, U2.4 (IO4)
TX: TX.TP, U2.25 (TXD0/GPIO16)
USB_D+: D2.1 (I/O1_1), U2.14 (IO13)
USB_D-: D2.3 (I/O2_1), U2.13 (IO12)
VBAT: C2_BAT.1, MCP_73831.3 (VBAT), Q1.3 (D), U1.2 (CELL), U1.3 (VDD), V_BAT.TP
VBUS: C1_BAT.1, C4_USB.1, C5_USB.1, CHG_LED.A, D1.2 (ANODE), D2.5 (VBUS), MCP_73831.4 (VIN), PFMF.050.1.2, Q1.1 (G), R1_PWRUSB.2, V_BUS.TP
VRTC: C8.1, C10_SUPERCAP.2, R_CAPACITOR.1, U3.14 (VBAT)
VUSB: J2.A4, J2.A9, J2.B4, J2.B9, PFMF.050.1.1

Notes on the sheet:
SD CARD
LI-PO BATTERY CHARGING CONTROLLER
ESP32 C6
VOLTAGE SUPERVISOR + RESET & BOOT / IO BUTTON
ENVIRONMENTAL SENSOR
EPD POWER
E-PAPER DISPLAY HEADER
RTC MODULE
TEST PADS
EXTERNAL NOR FLASH 64MB
SPI ESD PROTECTION LINES
LDO VOLTAGE REGULATOR
USB-C CONNECTOR & ESD PROTECTION
DISPLAY TYPE SELECTOR
EPAPER DRIVE CIRCUIT
BATTERY CHARGE LEVEL

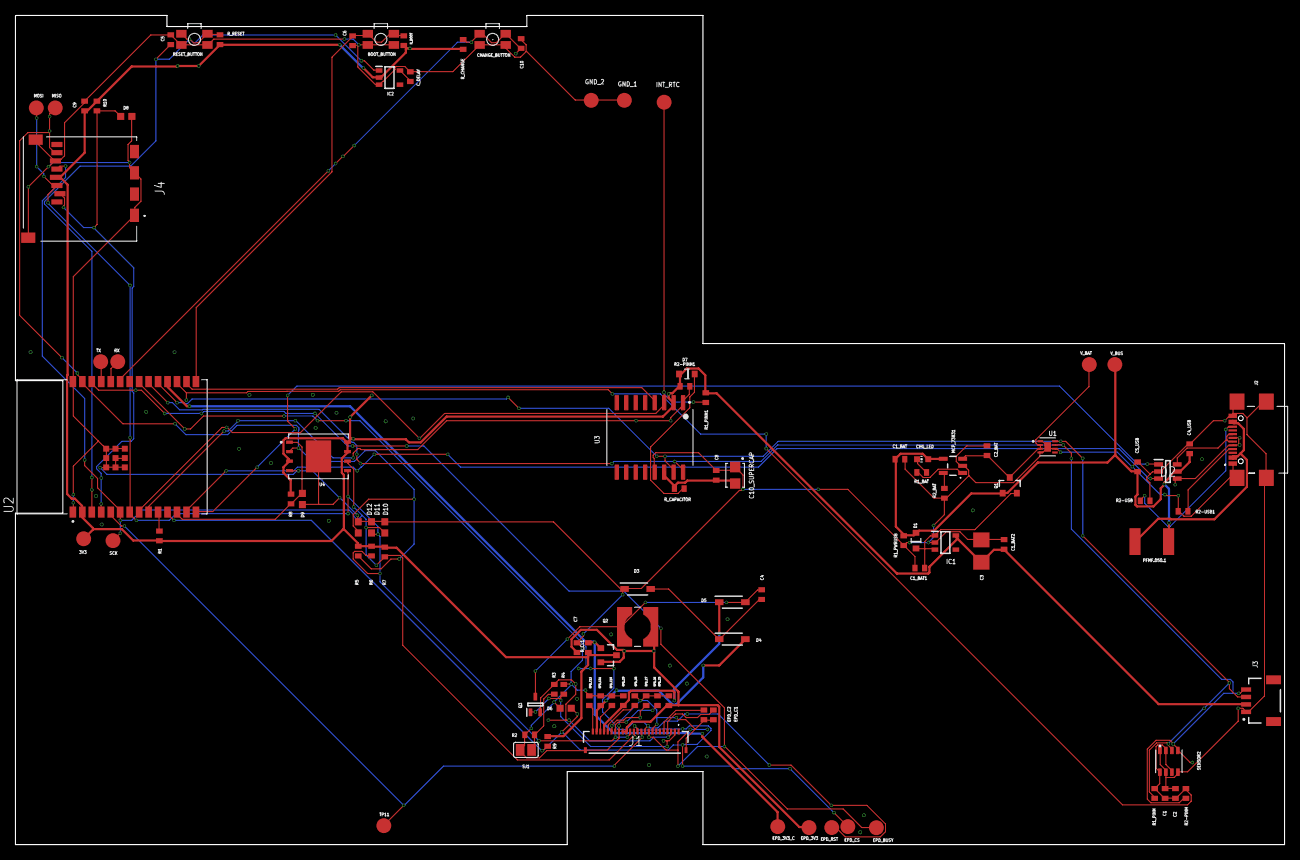
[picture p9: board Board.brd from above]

Board: 2 copper layers, 170.2 x 111.2 mm, 103 parts (0 on the bottom side), 55 nets.

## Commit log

2025-04-06 Added all files
    [Board.brd, PnP_Proiect v59_front.csv, Proiect v59.csv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]
2025-04-13 Fixed issues
    [PnP_Proiect v59_front.csv, Proiect v59.csv]
2025-04-14 updated sschematic and board
    [Board.brd, Schematic.sch]
2025-04-14 new board
    [Board.brd]

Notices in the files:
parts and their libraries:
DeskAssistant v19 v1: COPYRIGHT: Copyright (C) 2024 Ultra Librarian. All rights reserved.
